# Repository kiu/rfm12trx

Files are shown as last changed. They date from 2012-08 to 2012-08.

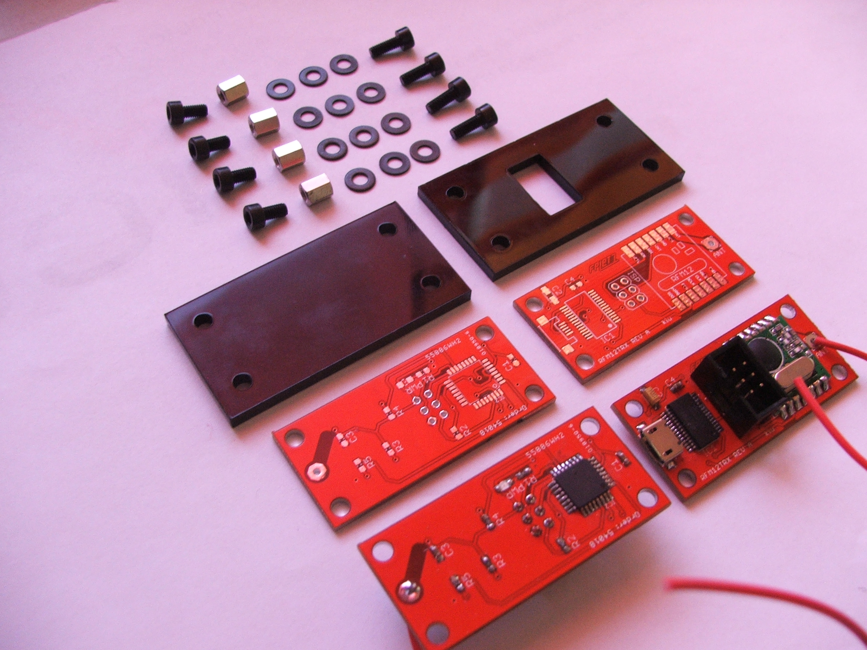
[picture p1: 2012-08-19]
media/rfm12trx-parts.jpg

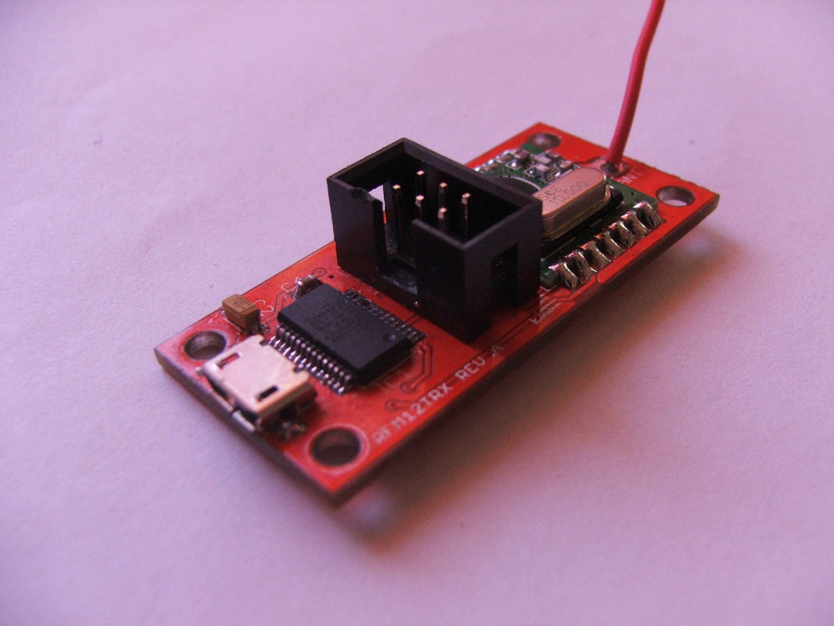
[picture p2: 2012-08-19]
media/rfm12trx-pcb-populated-top.jpg

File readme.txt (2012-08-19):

rfm12trx - A simple RFM12 433Mhz transceiver
http://schoar.de/tinkering/rfm12trx

1. Flash the RT232RL through USB
    http://www.ftdichip.com/Support/Utilities.htm#FT_Prog
    See firmware/rfm12trx_ftprog.xml (12Mhz on CBUS0)

2. Flash the ATMega8 through ISP
    make fuse
    make program

3. Send/Receive hex strings via ttyUSBx, e.g. screen /dev/ttyUSB0 115200

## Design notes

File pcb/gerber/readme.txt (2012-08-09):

Order: 54018

QTY: 10
Layer: 2
PCB Thickness: 1.6mm
PCB Dimension: 50x50mm (22x48mm)
PCB Color: red
Surface: Hasl
E-Test: 50%

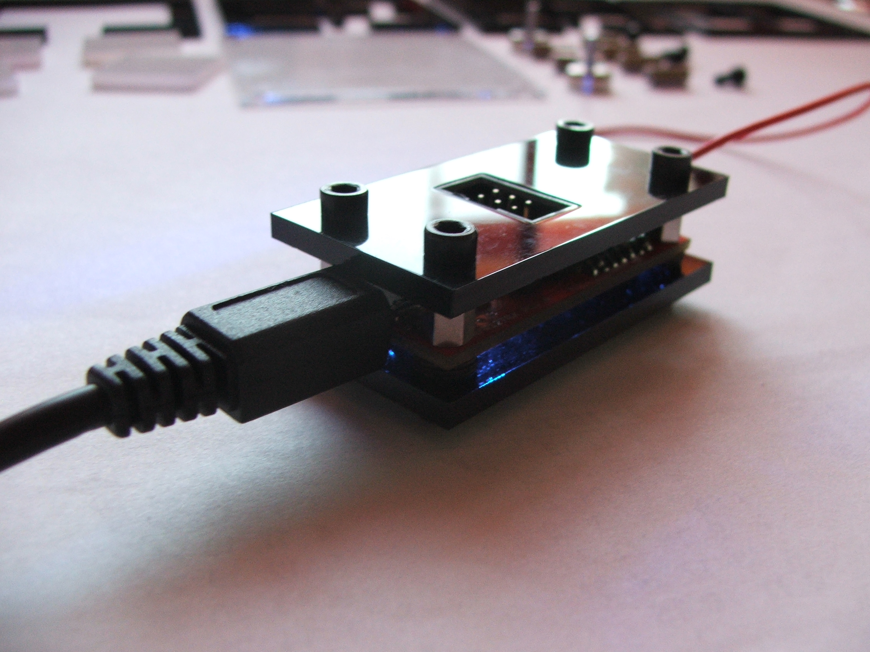
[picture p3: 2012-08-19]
media/rfm12trx.jpg

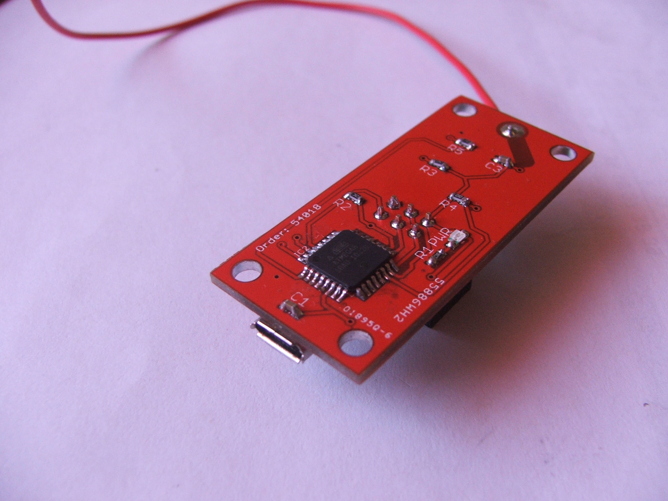
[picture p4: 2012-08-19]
media/rfm12trx-pcb-populated-bottom.jpg

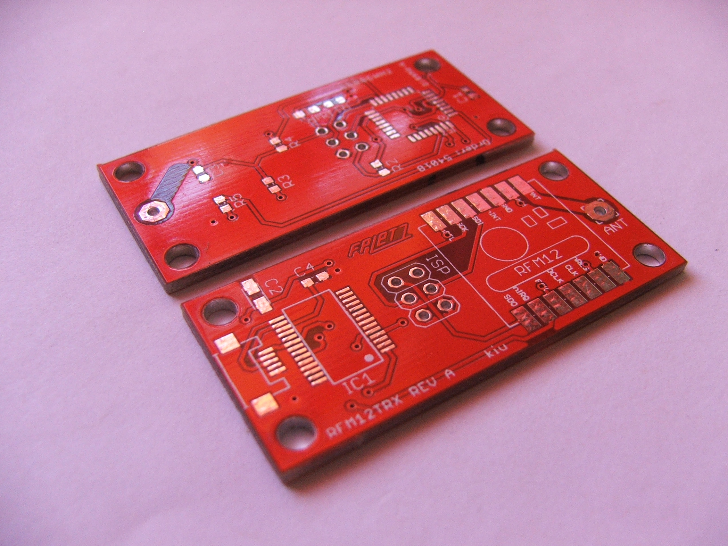
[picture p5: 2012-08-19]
media/rfm12trx-pcb.jpg

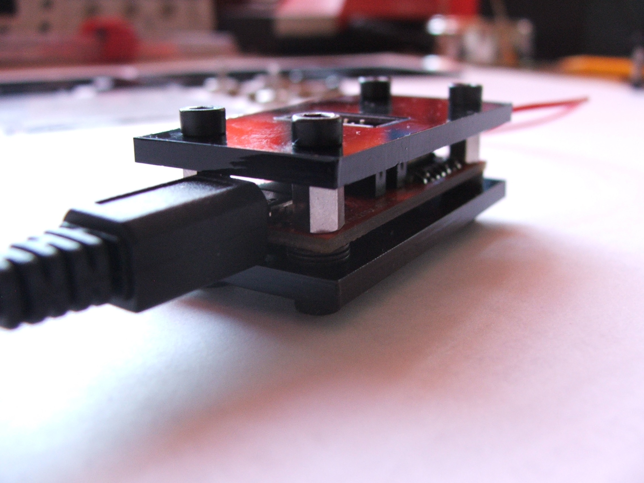
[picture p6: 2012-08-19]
media/rfm12trx-cased.jpg

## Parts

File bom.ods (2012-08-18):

Ordered | Description | Qty | Price | Price (sum) | Id | Link
x | 10x FT232RL | 1 | 23.17 € | 23.17 € | polida2008 | http://www.ebay.de
x | Micro USB | 10 | 1.13 € | 11.25 € | ESB227110100Z | http://www.tme.eu
x | SMD ATMega8-16 TQFP-32 | 10 | 1.82 € | 18.20 € | ATMEGA8-16AU | http://www.tme.eu
x | RFM12 | 10 | 4.58 € | 45.80 € | RFM12-433-S1 | http://www.tme.eu
x | Chip LED 0805 blue | 10 | 0.16 € | 1.60 € | OF-SMD2012B | http://www.tme.eu
x | (40x) SMD 100nF | 100 | 0.01 € | 0.69 € | 0603YC104KAT2A | http://www.tme.eu
x | (25x) SMD Tantal 10uF A | 25 | 0.10 € | 2.50 € | TAJA106K006R | http://www.tme.eu
x | (10x) SMD 100 | 100 | 0.01 € | 0.87 € | SMD0603-100R-1% | http://www.tme.eu
x | (30x) SMD 10k | 100 | 0.01 € | 0.87 € | SMD0603-10K-1% | http://www.tme.eu
x | (10x) SMD 100k | 100 | 0.01 € | 0.87 € | SMD0603-100K-1% | http://www.tme.eu
x | Distanzhülsen, Metall, M3, 6mm | 40 | 0.15 € | 5.88 € | TFF-M3X6/DR113 | http://www.tme.eu
x | Shipping | 1 | 5.90 € | 5.90 € | - | http://www.tme.eu
x | Wannenstecker, 6-polig, gerade | 10 | 0.16 € | 1.60 € | WSL 6G | http://www.reichelt.de
x | Shipping | 1 | 5.60 € | 5.60 € | - | http://www.reichelt.de
x | 50x (40) DIN 912 A2 M3X6 SB | 1 | 4.99 € | 4.99 € | 912236SB | http://www.screwsandmore.de
x | 50x (40) DIN 912 A2 M3X8 SB | 1 | 4.99 € | 4.99 € | 912238SB | http://www.screwsandmore.de
x | 50x (100) DIN 125 A2 3,2 SB | 2 | 2.49 € | 4.98 € | 125232SB | http://www.screwsandmore.de
x | 25x (20) DIN 125 A2 3,2 SB | 1 | 1.49 € | 1.49 € | 125232SB | http://www.screwsandmore.de
x | Shipping | 1 | 4.50 € | 4.50 € | - | http://www.screwsandmore.de
x | black 9H01 330x120x3 | 1 | 8.00 € | 8.00 € | - | http://www.plexihandel.de
x | Lasertime | 1 | 10.00 € | 10.00 € | - | http://miuc.ccc.de
x | PCB | 1 | 17.00 € | 17.00 € | - | http://www.seeedstudio.com
x | Shipping | 1 | 0.00 € | 0.00 € | - | http://www.seeedstudio.com
 |  |  |  | SUM
 |  |  |  | 180.75 € | for 10 pcs

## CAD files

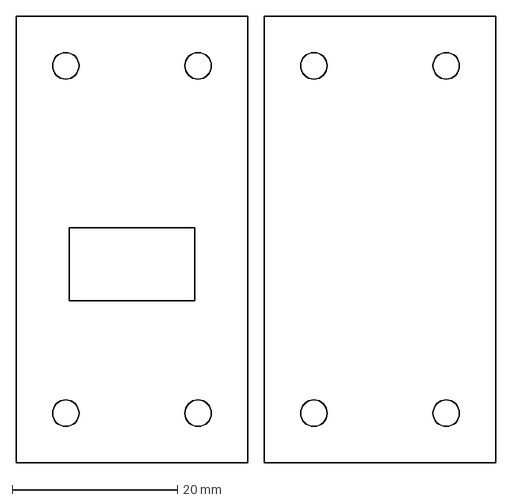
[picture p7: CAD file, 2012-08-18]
mech/rfm12trx-single.dxf
58.0 x 54.0 mm

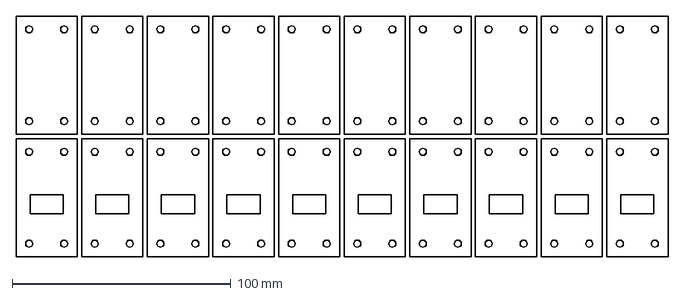
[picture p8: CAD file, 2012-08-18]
mech/rfm12trx-multi.dxf
298.0 x 110.0 mm

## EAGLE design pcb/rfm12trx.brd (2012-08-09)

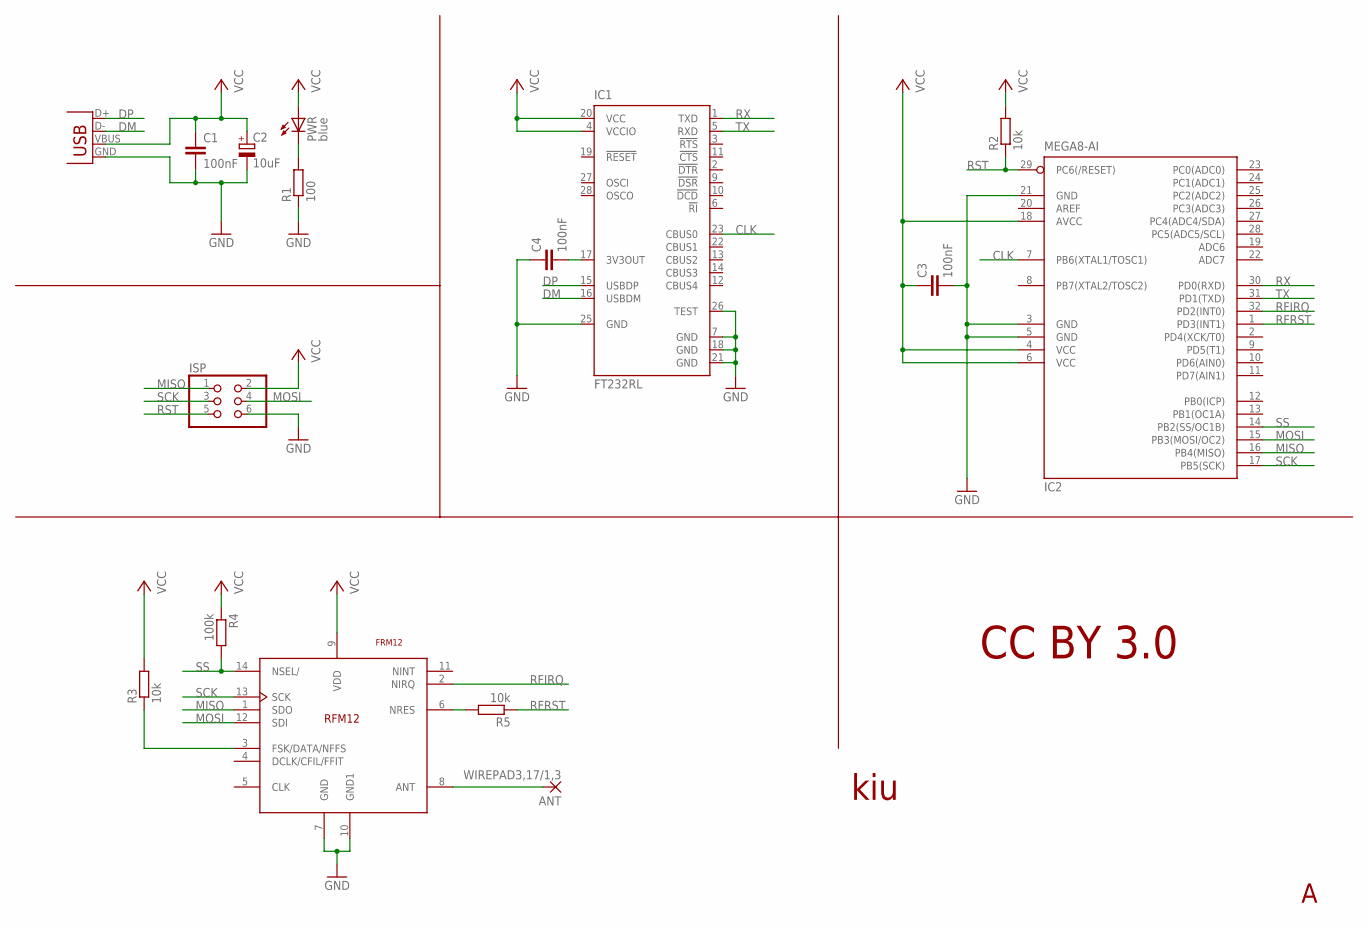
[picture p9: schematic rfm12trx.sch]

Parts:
ANT: WIREPAD3,17/1,3; 3,17/1,3
C1, C3, C4: 100nF; C0603
C2: 10uF; CT3216
IC1: FT232RL; SSOP28
IC2: MEGA8-AI; TQFP32-08
ISP: PINHD-2X3; 2X03
PWR: blue; CHIP-LED0805
R1: 100; R0603
R2, R3, R5: 10k; R0603
R4: 100k; R0603
U$1: FRM12; RFM12
X1: USB-MICROB

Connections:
CLK: IC1.23 (CBUS0), IC2.7 (PB6(XTAL1/TOSC1))
DM: IC1.16 (USBDM), X1.D-
DP: IC1.15 (USBDP), X1.D+
GND: C1.2, C2.-, C3.2, C4.1, IC1.7 (GND), IC1.18 (GND), IC1.21 (GND), IC1.25 (GND), IC1.26 (TEST), IC2.3 (GND), IC2.5 (GND), IC2.21 (GND), ISP.6, R1.1, U$1.7 (GND), U$1.10 (GND1), X1.GND
MISO: IC2.16 (PB4(MISO)), ISP.1, U$1.1 (SDO)
MOSI: IC2.15 (PB3(MOSI/OC2)), ISP.4, U$1.12 (SDI)
unnamed: PWR.C, R1.2
unnamed: C4.2, IC1.17 (3V3OUT)
unnamed: R3.1, U$1.3 (FSK/DATA/NFFS)
unnamed: R5.2, U$1.6 (NRES)
unnamed: ANT.1, U$1.8 (ANT)
RFIRQ: IC2.32 (PD2(INT0)), U$1.2 (NIRQ)
RFRST: IC2.1 (PD3(INT1)), R5.1
RST: IC2.29 (PC6(/RESET)), ISP.5, R2.1
RX: IC1.1 (TXD), IC2.30 (PD0(RXD))
SCK: IC2.17 (PB5(SCK)), ISP.3, U$1.13 (SCK)
SS: IC2.14 (PB2(SS/OC1B)), R4.2, U$1.14 (NSEL/)
TX: IC1.5 (RXD), IC2.31 (PD1(TXD))
VCC: C1.1, C2.+, C3.1, IC1.4 (VCCIO), IC1.20 (VCC), IC2.4 (VCC), IC2.6 (VCC), IC2.18 (AVCC), ISP.2, PWR.A, R2.2, R3.2, R4.1, U$1.9 (VDD), X1.VBUS

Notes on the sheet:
CC BY 3.0
kiu

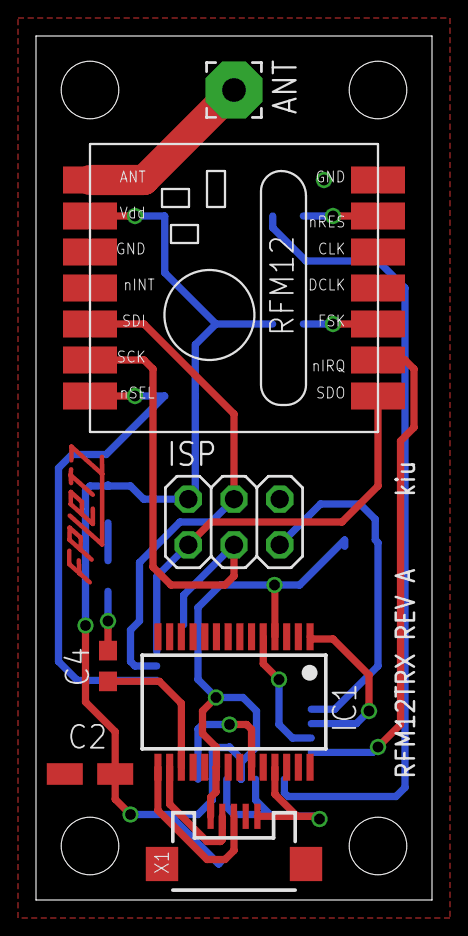
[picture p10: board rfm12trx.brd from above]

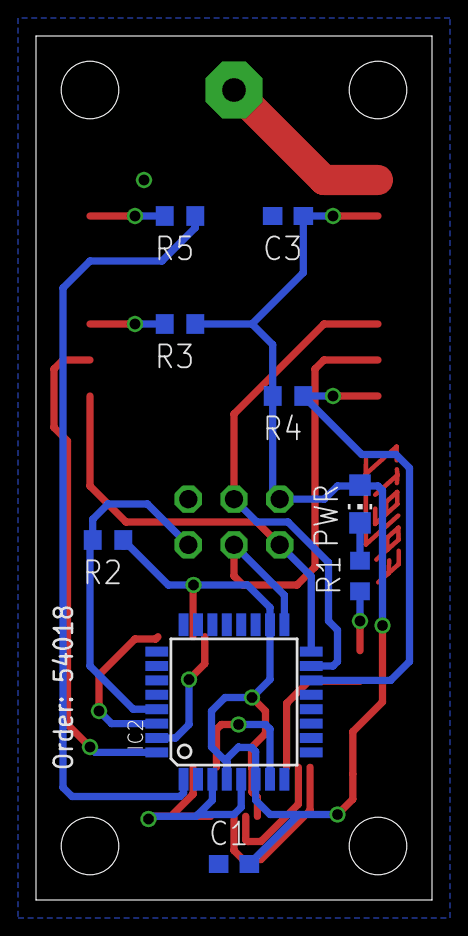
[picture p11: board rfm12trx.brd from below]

Board: 2 copper layers, 22.0 x 48.0 mm, 16 parts (9 on the bottom side), 19 nets.

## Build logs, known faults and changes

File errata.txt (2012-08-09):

PCB
	- USB connector footprint is missing two holes
	- LED, C2 and ISP silkscreen missing orientation marker

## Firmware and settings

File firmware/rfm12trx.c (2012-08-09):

/*
 * rfm12trx http://schoar.de/tinkering/rfm12trx
*/

#include "rfm12trx.h"

#include <stdlib.h>
#include <stdio.h>
#include <avr/io.h>
#include <avr/interrupt.h>
#include <avr/sleep.h>
#include <util/delay.h>

#include "lib/global.h"
#include "lib/uart/uart.h"
#include "lib/rfm12/rfm12.h"

unsigned char tx_buf[RFM12_DATA_LENGTH];
uint8_t tx_pos = 0;

uint8_t tx_high;
uint8_t tx_low;
uint8_t tx_toggle;

uint8_t tx_ready = 0;

uint8_t hexconvert(uint8_t ascii) {
    if (ascii >= '0' && ascii <= '9') {
	return ascii - 48;
    }

    if (ascii >= 'A' && ascii <= 'F') {
	return ascii - 55;
    }

    if (ascii >= 'a' && ascii <= 'f') {
	return ascii - 87;
    }

    return 255;
}

void read(void) {
    if (tx_ready == 1) {
	return;
    }

    while(1) {

	unsigned int ci = uart_getc();

	if (ci & UART_NO_DATA) {
	    return;
	}

	uint8_t cc = (uint8_t)ci;

	if (hexconvert(cc) != 255) {
	    if (tx_toggle == 0) {
		tx_high = hexconvert(cc);
	    } else {
		tx_low = hexconvert(cc);
		tx_buf[tx_pos++] = tx_high * 16 + tx_low;
	    }
	    tx_toggle ^= 1;
	}

	if (cc == '\r' || cc == '\n' || tx_pos >= sizeof(tx_buf) - 1) {
		tx_ready = 1;
		tx_toggle = 0;
		return;
	}

    }
}

void rx(void) {
    uint8_t state;

    state = rfm12_rxstart();

    unsigned char tmp[RFM12_DATA_LENGTH];
    state = rfm12_rxfinish(tmp);
    if (state == 0) {
	return;
    }
    if (state == 255) {
	return;
    }
    if (state == 254) {
	rfm12_allstop();
	return;
    }

    char out[16];
    sprintf(out, "RX: [%02x] ", state);
    uart_puts(out);
    for (uint8_t i=0; i < state; i++) {
	sprintf(out,"%02x", tmp[i]);
	uart_puts(out);
    }
    uart_puts("\r\n");
}

void tx(void) {
    if (tx_ready == 0) {
	return;
    }
    tx_ready = 0;

    uint8_t len = tx_pos;
    tx_pos = 0;
    if (len == 0) {
	return;
    }

    rfm12_allstop();
    if (rfm12_txstart(tx_buf, len) != 0) {
	return;
    }

    while (rfm12_txfinished() != 0) {
    }

    char out[16];
    sprintf(out, "TX: [%02x] ", len);
    uart_puts(out);
    for (uint8_t i=0; i < len; i++) {
	sprintf(out,"%02x", tx_buf[i]);
	uart_puts(out);
    }
    uart_puts("\r\n");
}

int main (void) {

    _delay_ms(2000);

    sei();

    uart_init(UART_BAUD_SELECT_DOUBLE_SPEED(UART_BAUD_RATE, F_CPU)); 
    uart_puts("\r\nrfm12trx http://schoar.de/tinkering/rfm12trx\r\n");

    rfm12_init();

    rfm12_setfreq(RFM12_FREQ(434.32));
    rfm12_setbandwidth(RxBW200, LNA_6, RSSI_79);
    rfm12_setbaud(19200);
    rfm12_setpower(PWRdB_0, TxBW105);

    while(1) {
	read();

	if (tx_ready != 0) {
	    tx();
	} else {
	    rx();
	}
    }

}

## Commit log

2012-08-18 Adding BOM
    [bom.ods]
2012-08-18 Adding mechnical files
    [rfm12trx-multi.dxf, rfm12trx-single.dxf]

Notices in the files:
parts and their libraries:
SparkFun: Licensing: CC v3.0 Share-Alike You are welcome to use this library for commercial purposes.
